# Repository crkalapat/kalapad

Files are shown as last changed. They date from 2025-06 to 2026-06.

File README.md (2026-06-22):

# Kalapad

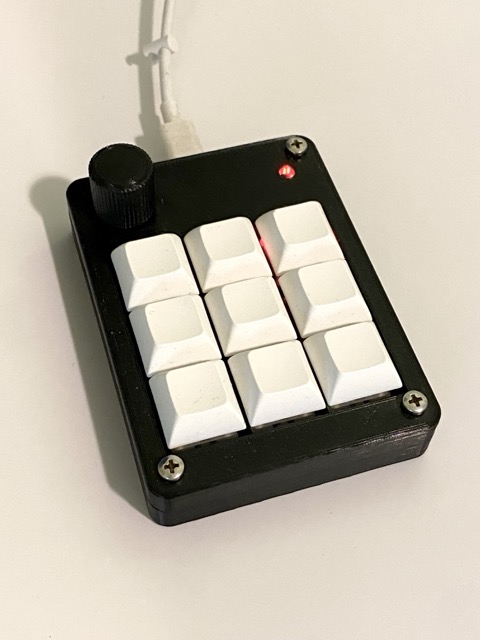
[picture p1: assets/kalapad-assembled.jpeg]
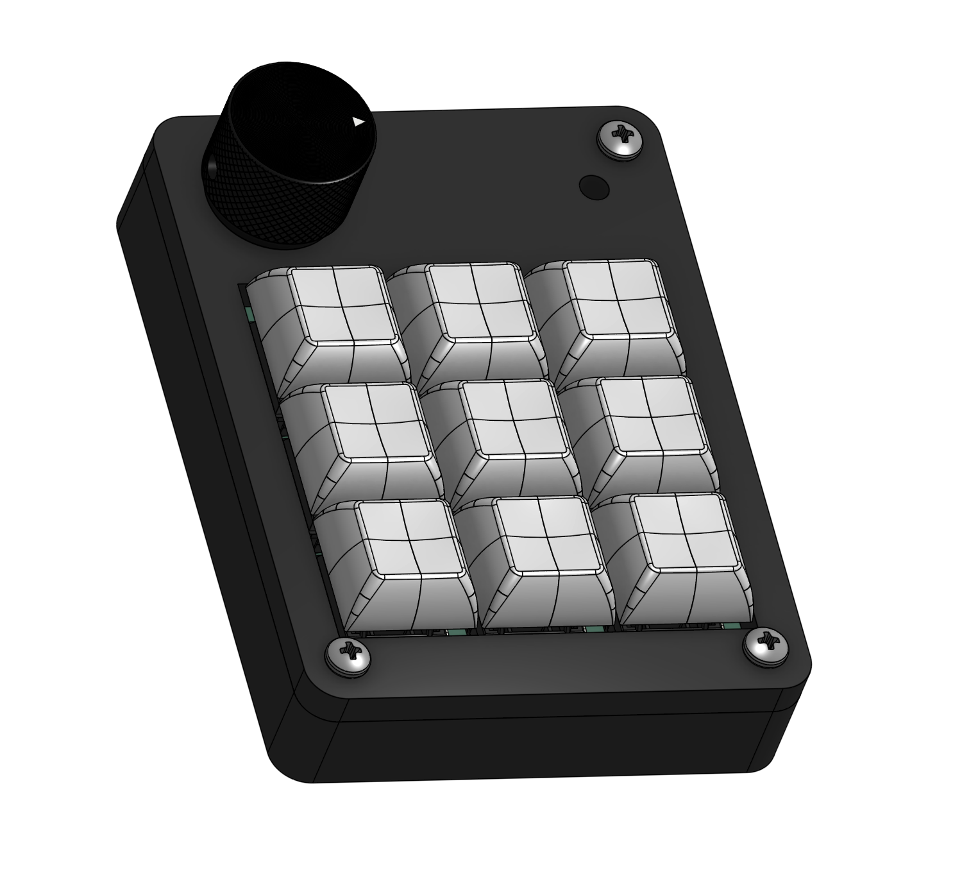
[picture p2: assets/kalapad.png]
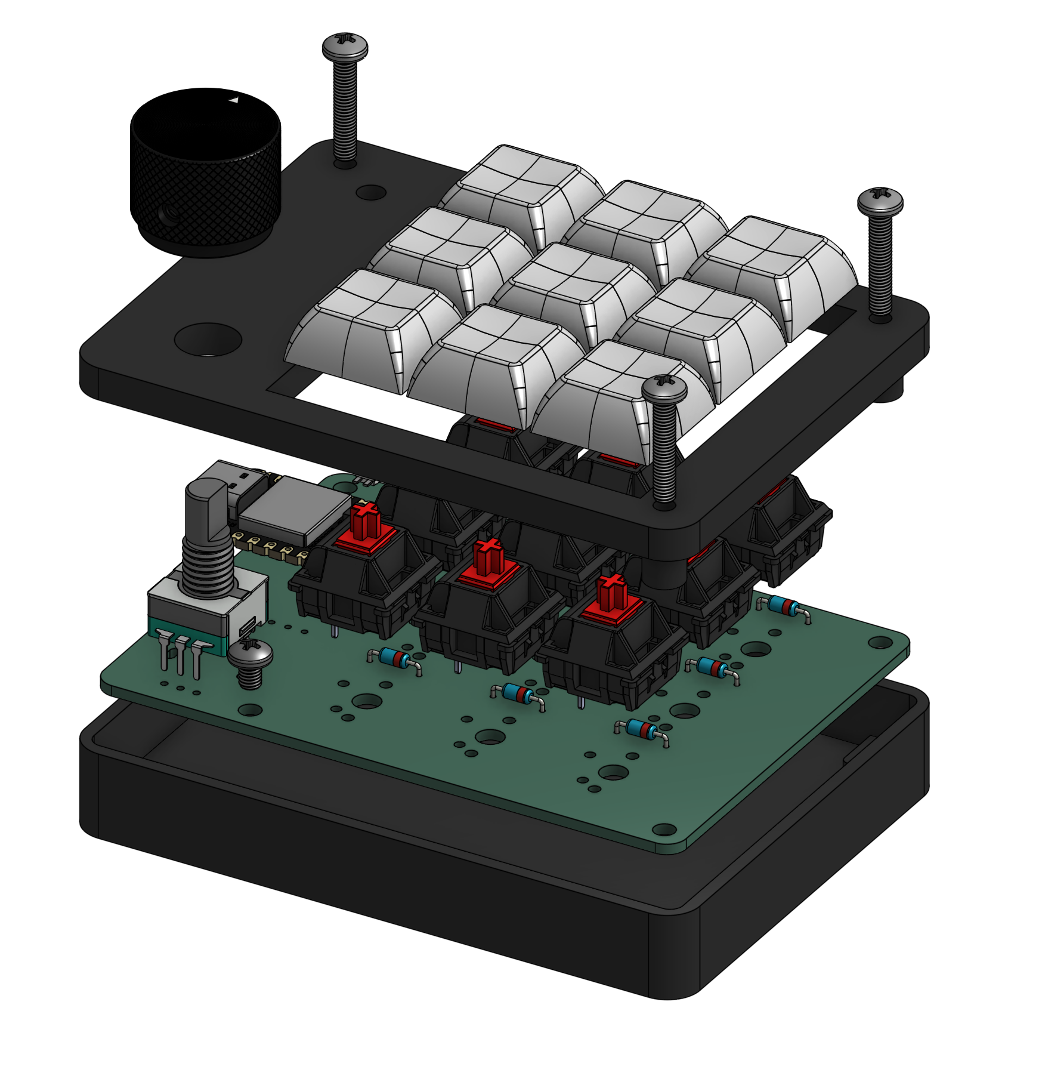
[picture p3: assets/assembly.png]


_A custom QMK-based 9 key macropad_

## Features

- 9 programmable macro switches
- Cherry MX Switch compatibility
- SK6812-E RGB LED indicator light
- EC11 Rotary Encoder for volume control
- Matrix-style switch layout

## Demo

https://github.com/user-attachments/assets/4e5cf57b-7511-4118-89fe-79310d505cb6

## Design

### PCB

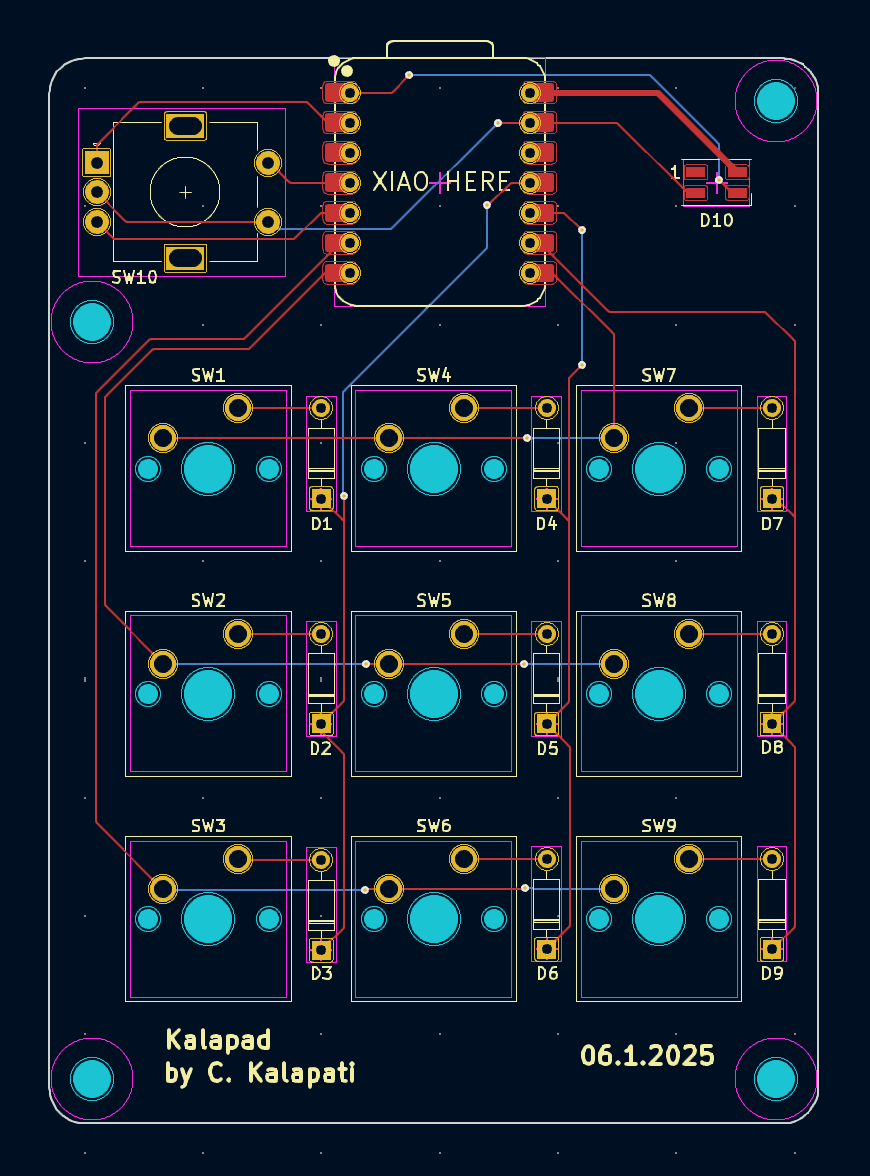
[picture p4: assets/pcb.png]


### Schematic

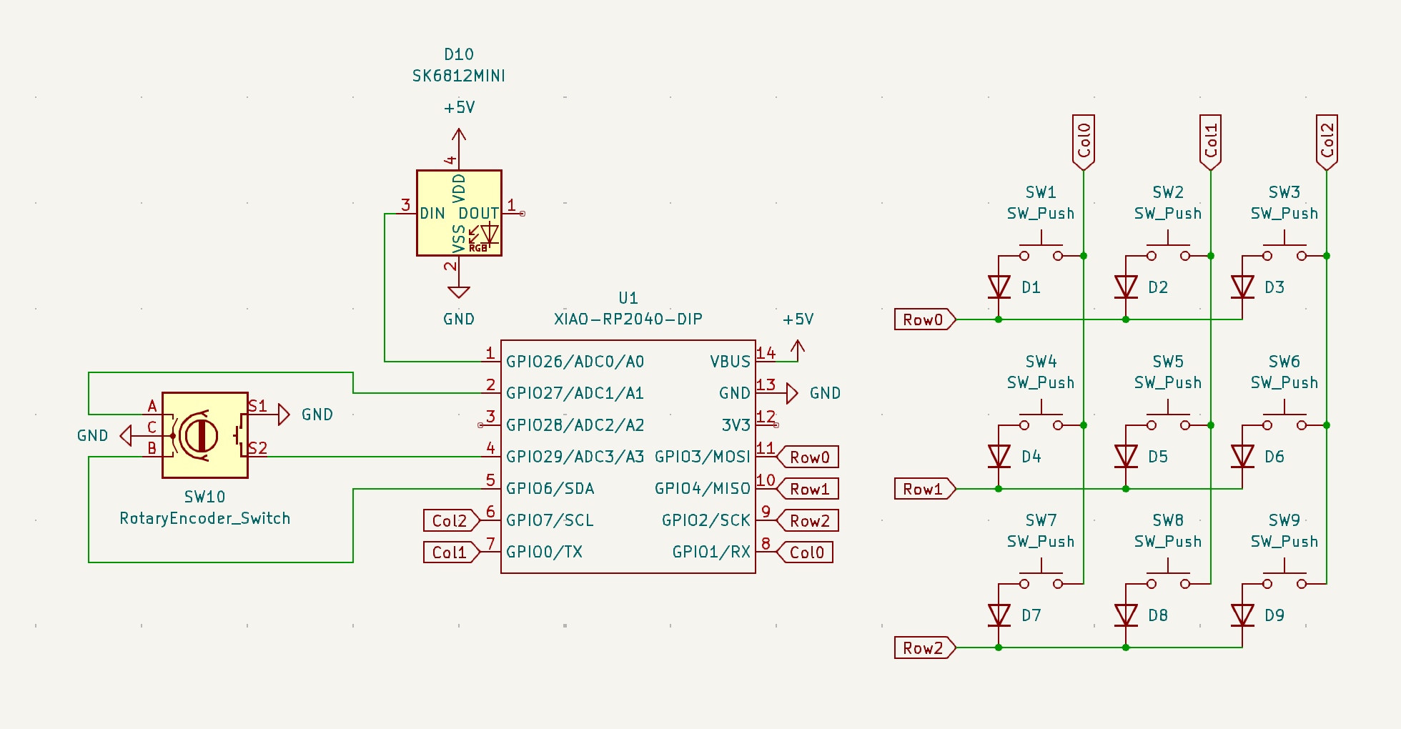
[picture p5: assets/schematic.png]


## BOM

- 9x Cherry MX Switches
- 1x SK6812-E LED
- 1x EC11 Rotary Encoder
- 1x Seeed Studio XIAO RP2040
- 3x M3x16mm screws
- 1x M3x4mm screw
- 1x 3D-Printed Case (Top and Bottom)
- 1x PCB

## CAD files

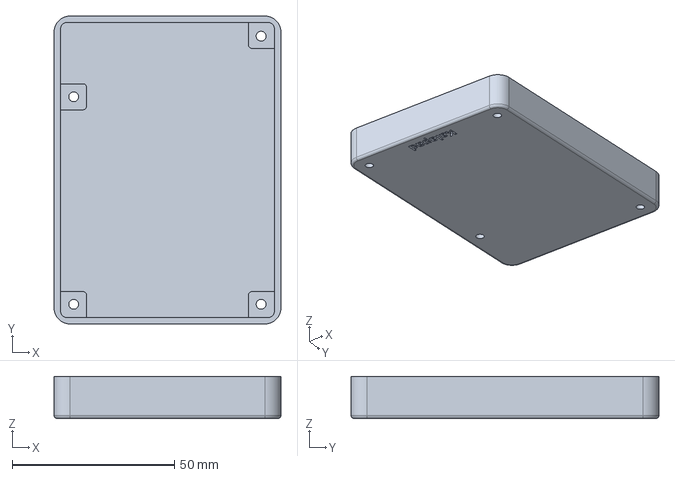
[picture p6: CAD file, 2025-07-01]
production/Bottom.step
70.0 x 95.0 x 13.0 mm

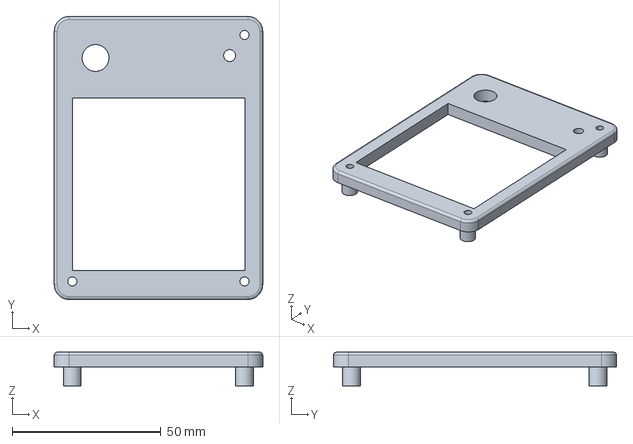
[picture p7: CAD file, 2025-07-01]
production/Top.step
70.0 x 95.0 x 11.3 mm

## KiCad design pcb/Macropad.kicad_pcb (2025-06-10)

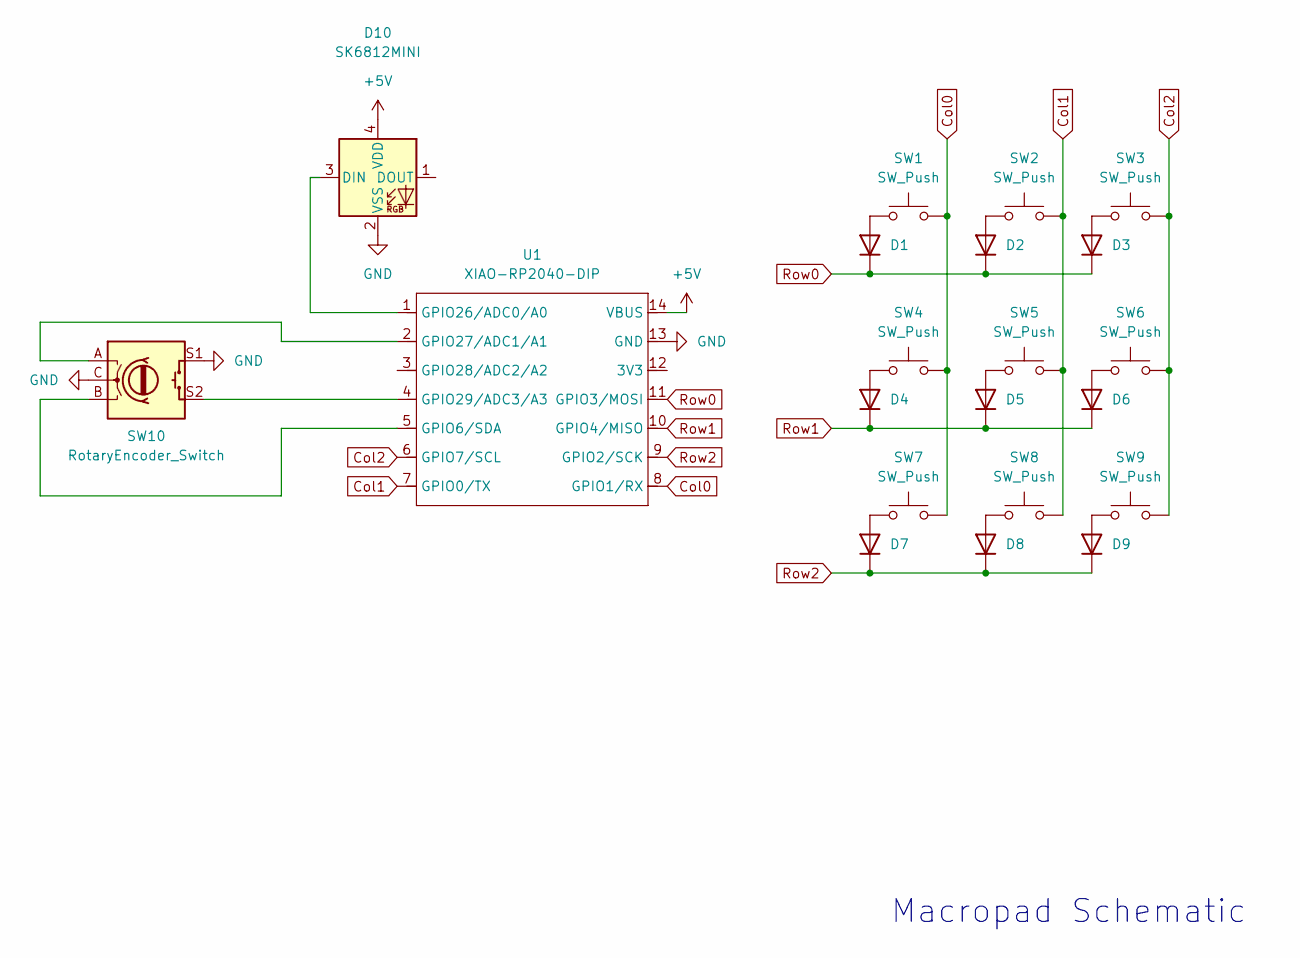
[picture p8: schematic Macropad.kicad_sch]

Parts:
D1, D2, D3, D4, D5, D6, D7, D8, D9: D_A-405_P5.08mm_Vertical_AnodeUp
D10: SK6812MINI; LED_SK6812MINI_PLCC4_3.5x3.5mm_P1.75mm
SW1, SW2, SW3, SW4, SW5, SW6, SW7, SW8, SW9: SW_Push; SW_Cherry_MX_1.00u_PCB
SW10: RotaryEncoder_Switch; RotaryEncoder_Alps_EC11E-Switch_Vertical_H20mm
U1: XIAO-RP2040-DIP

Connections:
+5V: D10.4 (VDD), U1.14 (VBUS)
Col0: SW1.2, SW4.2, SW7.2, U1.8 (GPIO1/RX)
Col1: SW2.2, SW5.2, SW8.2, U1.7 (GPIO0/TX)
Col2: SW3.2, SW6.2, SW9.2, U1.6 (GPIO7/SCL)
GND: D10.2 (VSS), SW10.C, SW10.S1, U1.13 (GND)
unnamed: D1.2 (A), SW1.1
unnamed: D2.2 (A), SW2.1
unnamed: D3.2 (A), SW3.1
unnamed: D4.2 (A), SW4.1
unnamed: D5.2 (A), SW5.1
unnamed: D6.2 (A), SW6.1
unnamed: D7.2 (A), SW7.1
unnamed: D8.2 (A), SW8.1
unnamed: D9.2 (A), SW9.1
unnamed: D10.3 (DIN), U1.1 (GPIO26/ADC0/A0)
unnamed: SW10.B, U1.5 (GPIO6/SDA)
unnamed: SW10.A, U1.2 (GPIO27/ADC1/A1)
unnamed: SW10.S2, U1.4 (GPIO29/ADC3/A3)
Row0: D1.1 (K), D2.1 (K), D3.1 (K), U1.11 (GPIO3/MOSI)
Row1: D4.1 (K), D5.1 (K), D6.1 (K), U1.10 (GPIO4/MISO)
Row2: D7.1 (K), D8.1 (K), D9.1 (K), U1.9 (GPIO2/SCK)

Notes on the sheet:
Macropad Schematic

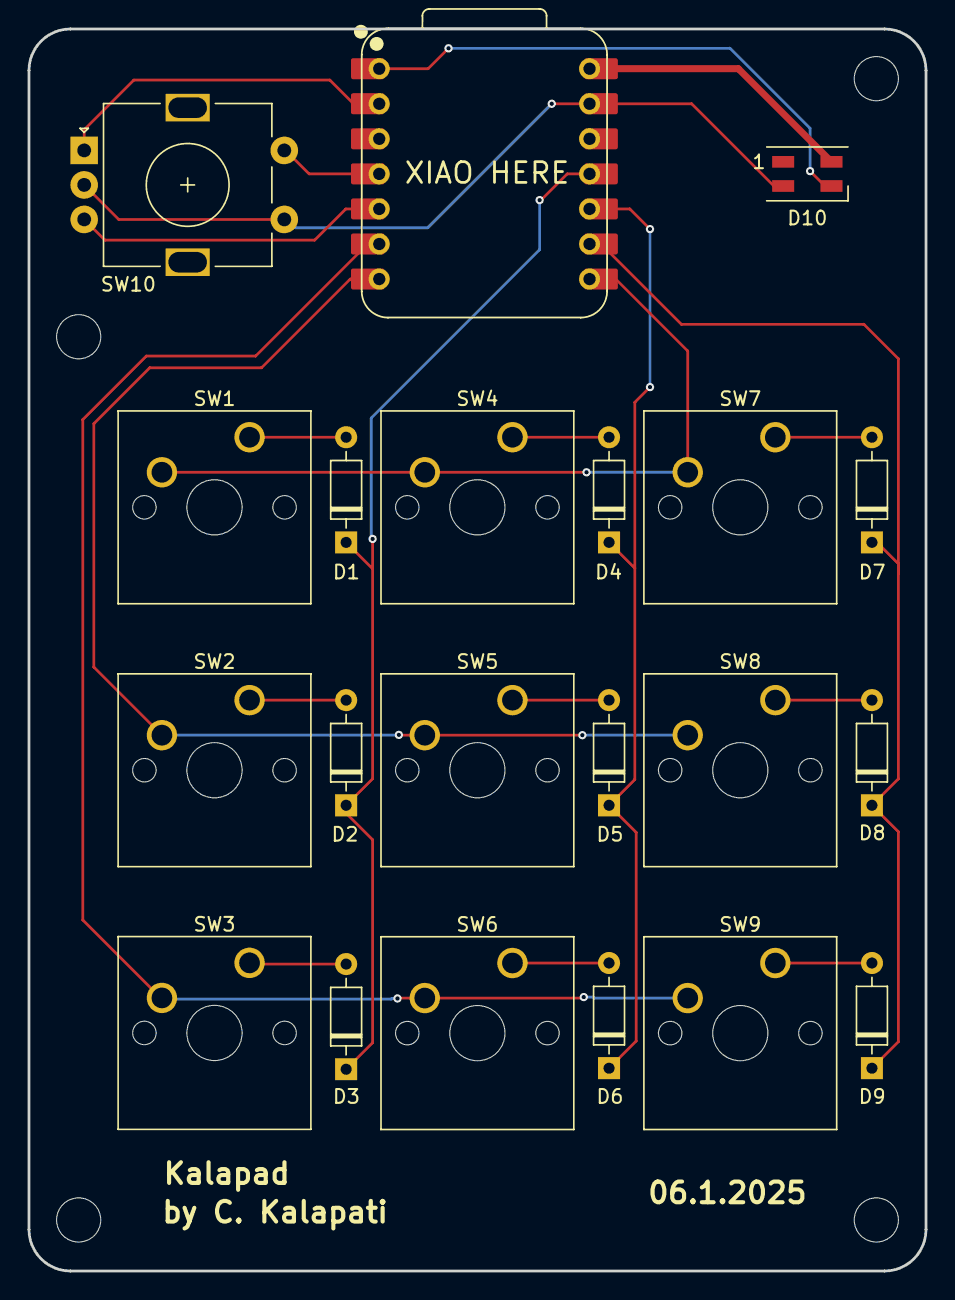
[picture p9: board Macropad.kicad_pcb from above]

Board: 2 copper layers, 65.0 x 90.0 mm, 21 parts (0 on the bottom side), 21 nets.

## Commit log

2025-06-09 Add images, case CAD files, README
    [Bottom.step, Top.step]
2025-06-09 Add assembly image to README
2025-06-10 Fix BOM
2025-06-10 Add PCB files
    [Macropad.kicad_pcb, Macropad.kicad_sch]
2025-06-10 Add assembly CAD, change README
2025-07-01 Add fillet edge
    [Bottom.step, Top.step]
2026-06-22 Add gitignore and assembled picture
